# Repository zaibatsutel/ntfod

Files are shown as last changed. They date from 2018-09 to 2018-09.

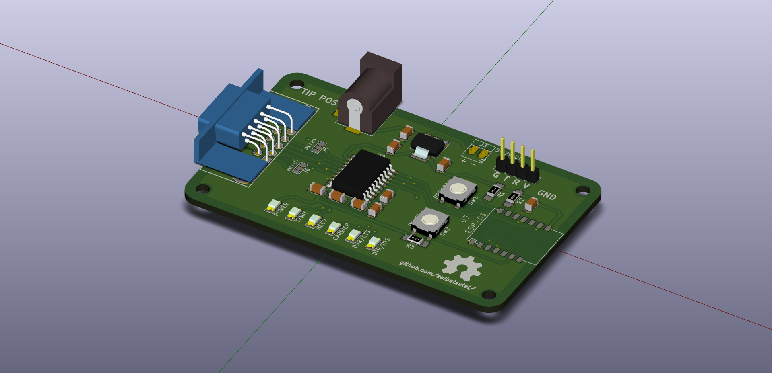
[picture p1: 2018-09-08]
boardshots/oblique-2018-09-08.png

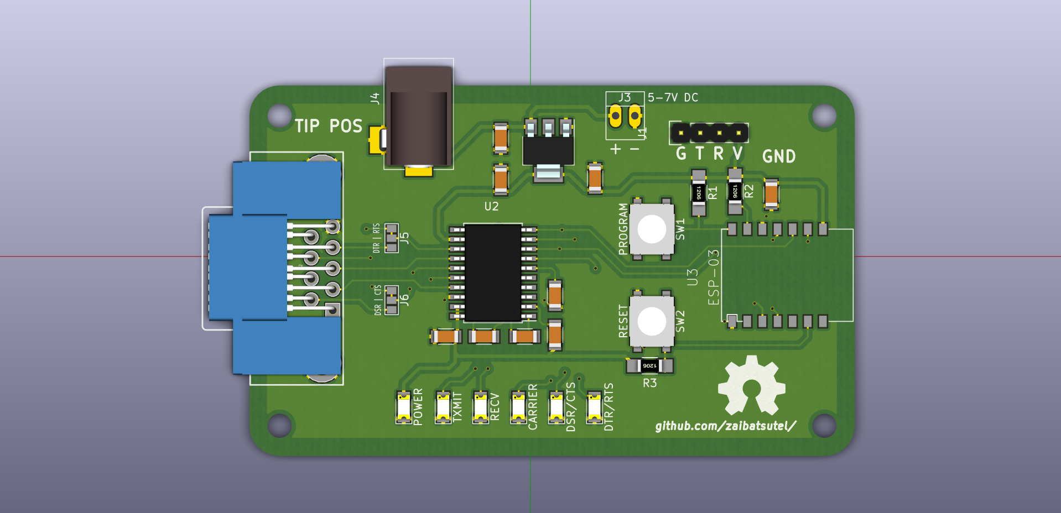
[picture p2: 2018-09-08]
boardshots/top-2018-09-08.png

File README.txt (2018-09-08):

HELLO INTERNET!

This is my version of the ever popular "connect your old computer to the
internet using wifi" project. 

This version uses (for now) the ESP-03, a slightly more broken out version
of the ESP-01. It has LEDs and stuff on it to show the state of control
registers and other things. 

The big thing that I wanted to implement here is that the flow control pins
are selectable!

There's some other things that I've done:

* I've used a MAX3386e (the SOIC20 version) so that I can make sure that I
have a good set of inputs and outputs. The big reason for this was so that
I can include a RING line (so you can dial into this!) and so that it had
all the various control lines that people integrated into their stuff.

Some day, I'd like to make this into a more product-like thing. 

The software is the apache2-licensed Zimodem from Bo Zimmerman. I'd like to
eventually have his software selectable in terms of what board it's being run
under so that there's fewer forks. His was designed with Commodore CBM machines
in mind -- mine is more build for the NEC Model 100s and friends. 

You can program this with the serial port that is included on the board if you
have a USB-Serial contrller, but you still have to populate the buttons for
program and reset.

Programming involves holding down program and reset, then releasing reset.
This will place the device into boot mode (as is the case with all the various
things that use the ESP8266.

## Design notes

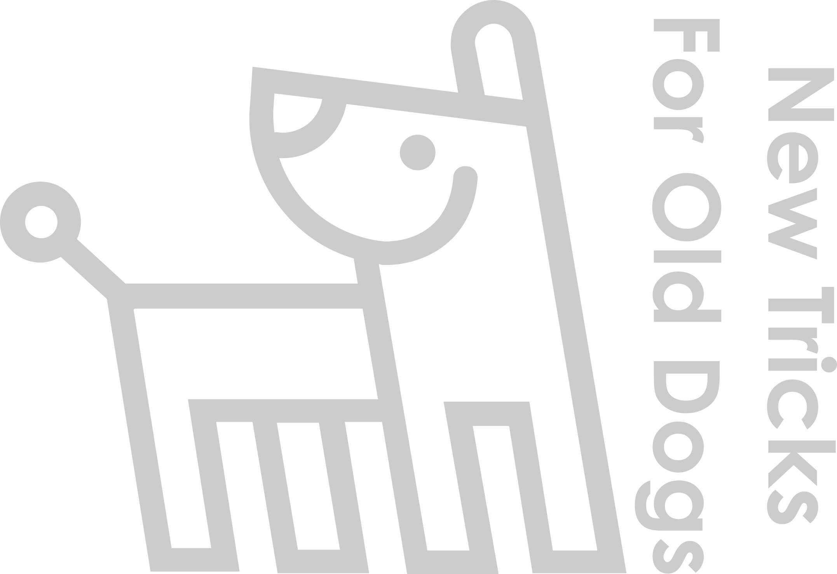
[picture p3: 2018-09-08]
graphics/path62.png

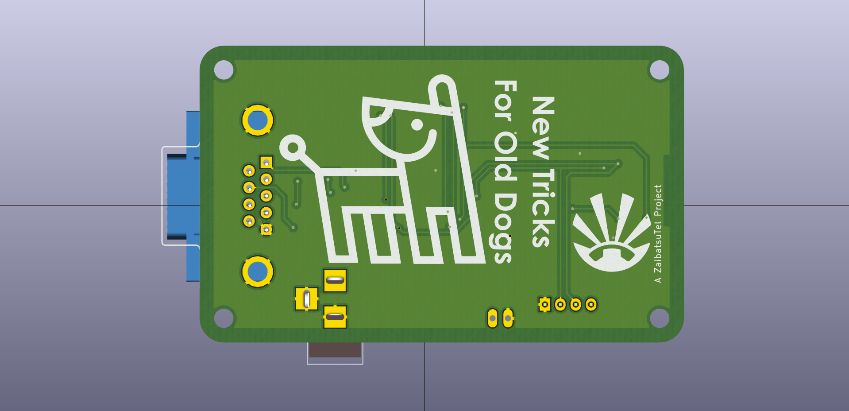
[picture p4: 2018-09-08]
boardshots/bottom-2018-09-08.png

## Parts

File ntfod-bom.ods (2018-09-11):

New Tricks for Old Dogs rev 2 initial BOM
reference | part | Part Number | DigiKey PN | Digikey qty1 | Digikey qty10 | Mouser PN | Mouser qty1 | Mouser qty10 | qty/board | Qty/10 | Digikey cost/1 | Digikey cost/10 | Mouser cost/1 | Mouser cost/10
D1-D6 | LED, 1206 smt | Lite-On LTST-C230KFKT | 160-2025-1-ND | $0.38 | $0.27 | 859-LTST-C230KFKT | $0.30 | $0.16 | 6 | 60 | $2.28 | $16.26 | $1.80 | $9.60
SW1 SW2 | SWITCH TACTILE SPST-NO 0.05A 12V | E-Switch TL3342F160QG/TR | EG2531CT-ND | $0.70 | $0.67 | 612-TL3342F160 | $0.66 | $0.63 | 2 | 20 | $1.40 | $13.40 | $1.32 | $12.60
U1 | IC REG LINEAR 3.3V 1A SOT223 | Diodes Incorporated AZ1117H-3.3TRE1 | AZ1117H-3.3TRE1DICT-ND | $0.47 | $0.35 | 621-AZ1117H-3.3TRE1 | $0.46 | $0.32 | 1 | 10 | $0.47 | $3.50 | $0.46 | $3.19
U2 | IC TXRX RS232 SPLIT SUPP 20SOIC | Texas Instruments TRS3386ECDWR | 296-25063-1-ND | $3.39 | $3.05 | 595-TRS3386ECDWR | $3.30 | $2.96 | 1 | 10 | $3.39 | $30.47 | $3.30 | $29.60
J2 | CONN D-SUB RCPT 9POS R/A SOLDER | Amphenol LD09S13A4GX00LF | 609-5189-ND | $0.98 | $0.86 | 649-LD09S13A4GX00LF | $0.99 | $0.86 | 1 | 10 | $0.98 | $8.60 | $0.99 | $8.64
J1 | CONN HEADER 4 POS 2.54 | Wurth 61300411121 | 732-5317-ND | $0.18 | $0.15 | 710-61300411121 | $0.18 | $0.15 | 1 | 10 | $0.18 | $1.53 | $0.18 | $1.53
J4 | CONN PWR JACK 2X5.5MM SOLDER | CUI PJ-002A | CP-002A-ND | $0.61 | $0.57 | 490-PJ-002A | $0.60 | $0.56 | 1 | 10 | $0.61 | $5.70 | $0.60 | $5.59
C2,C3,C4,C8 | Capacitor, 0.1ufd 1206 size | Wurth 885012208009 | 732-8086-1-ND | $0.11 | $0.10 | 710-885012208009 | $0.11 | $0.10 | 4 | 40 | $0.44 | $3.96 | $0.44 | $4.00
C1,C5,C7,C9,C6 | Capacitor 10ufd 1206 size | Taiyo-Yuden LMK316B7106KL-TD | 587-2596-1-ND | $0.30 | $0.21 | 963-LMK316BJ106ML-T | $0.29 | $0.13 | 5 | 50 | $1.50 | $10.35 | $1.45 | $6.40
R1,R2,R3 | Resistor, 10K 1206 SMT 5% | Rohm KTR18EZPJ103 | RHM10KPCT-ND | $0.15 | $0.14 | 755-KTR18EZPJ103 | $0.13 | $0.11 | 3 | 30 | $0.45 | $4.11 | $0.39 | $3.36
U3 | ESP8266 ESP-03 module | AI-thinker ESP-03 | N/A |  |  | N/A
 |  |  | DigiKey cost/1 | 11.7
 |  |  | DigiKey Cost/10 | 97.88
 |  |  | Mouser cost/1 | 10.93
 |  |  | Mouser cost/10 | 84.51
AliExpress vendors for ESP-03 module
1pc vendor A | $1.95 | https://www.aliexpress.com/store/product/1PC-ESP8266-serial-WIFI-model-ESP-03-Authenticity-Guaranteed-esp03/1735233_32641401163.html
10pc/lot via Mega Semiconductor | $22.00 | https://www.aliexpress.com/store/product/Free-Shipping-10pcs-lot-ESP8266-remote-serial-Port-WIFI-wireless-module-through-walls-Wang-ESP-03/808897_32713422494.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
1pc/lot via Mega Semiconductor | $2.15 | https://www.aliexpress.com/store/product/ESP8266-serial-WIFI-model-ESP-03-Authenticity-Guaranteed-ESP03-free-shipping/808897_32713916387.html
5pcs/lot via Best Choice | $12.40 | https://www.aliexpress.com/store/product/Free-shipping-5-PCS-ESP8266-SMD-serial-WIFI-industry-milepost-unbeatable-price-deep-Mingyang-Electronics-ESP/221555_3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
10pc/lot via Annousen | $32.00 | https://www.aliexpress.com/store/product/10-PCS-LOT-ESP8266-ESP-03-serial-WIFI-WIF-transceiver-wireless-remote-wireless-control-module-ESP/3632102_32854430232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
Cost to build 5 w/mouser | 54.65
Cost to build 5 w/digikey | 58.5
Mouser cost 5 + Aliexpress | $67.05 |  | Long lead time on ESP8266, 20-40 days!

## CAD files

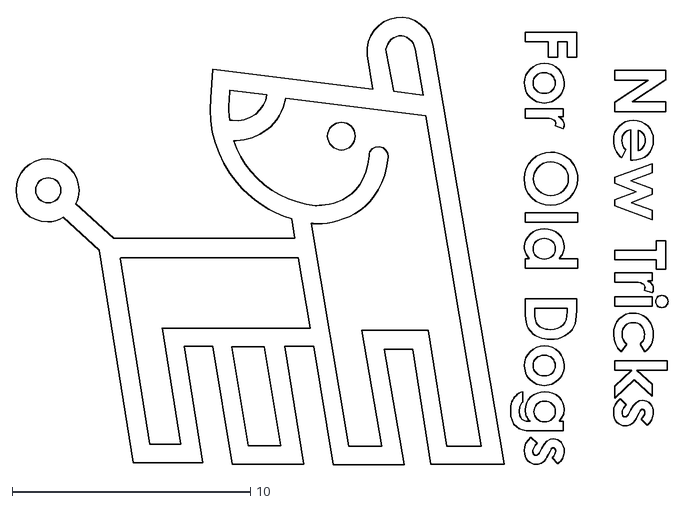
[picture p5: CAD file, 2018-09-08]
graphics/logo.dxf
27.4 x 18.8

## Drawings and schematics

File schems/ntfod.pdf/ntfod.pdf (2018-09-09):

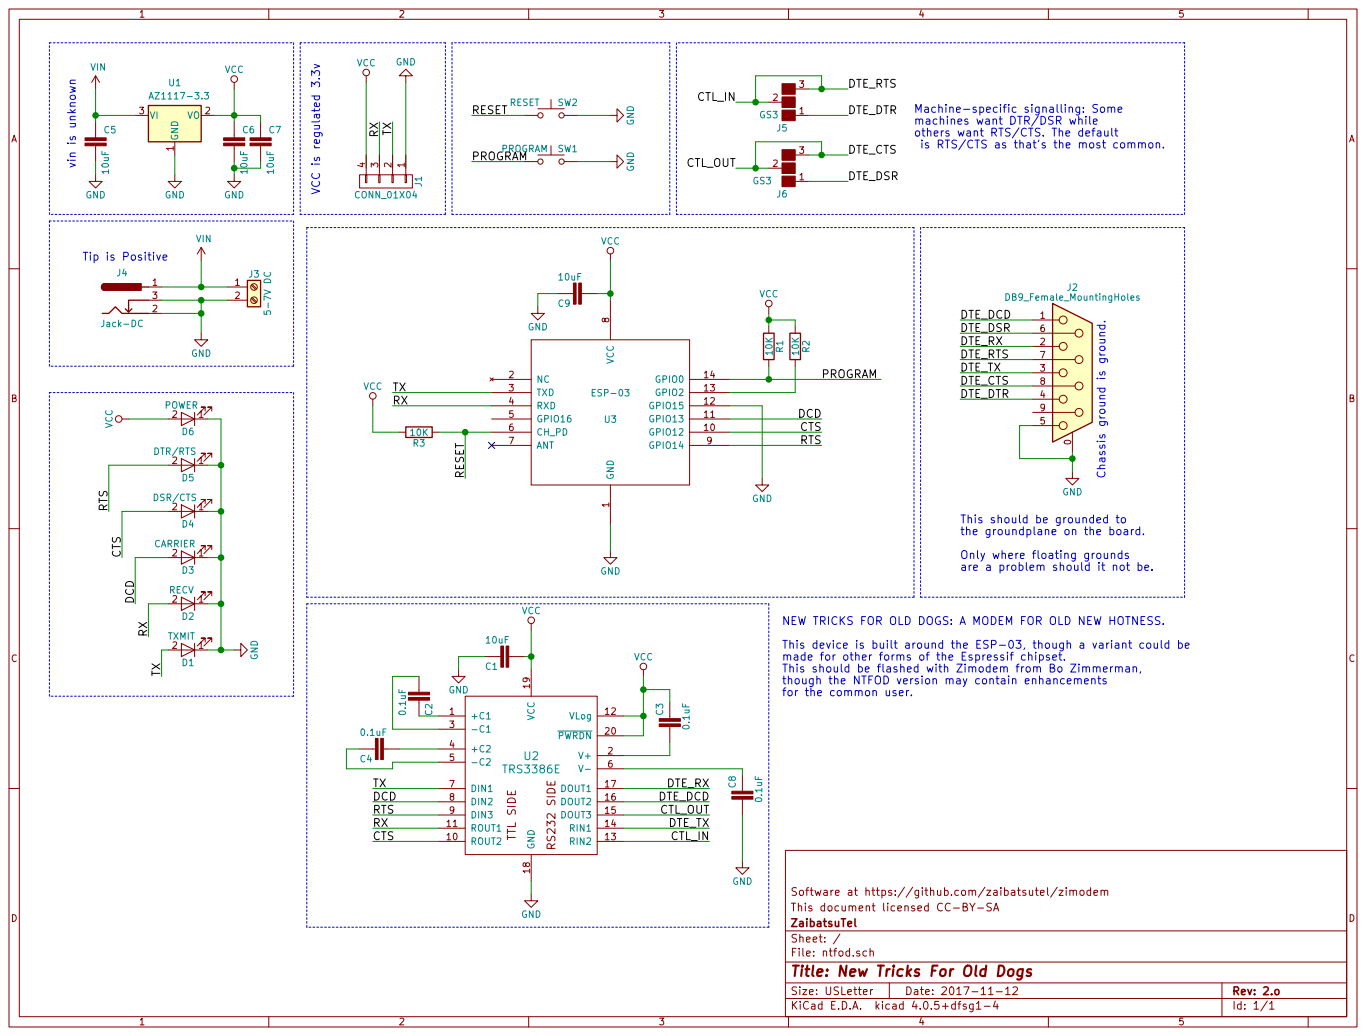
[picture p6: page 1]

Machine-specific signalling: Some
machines want DTR/DSR while
others want RTS/CTS. The default
is RTS/CTS as that's the most common.

This should be grounded to
the groundplane on the board.
Only where floating grounds
are a problem should it not be.

NEW TRICKS FOR OLD DOGS: A MODEM FOR OLD NEW HOTNESS.
This device is built around the ESP-03, though a variant could be
made for other forms of the Espressif chipset.
This should be flashed with Zimodem from Bo Zimmerman,
though the NTFOD version may contain enhancements

File: ntfod.sch Sheet: / ZaibatsuTel This document licensed CC-BY-SA

Id: 1/1 Title: New Tricks For Old Dogs

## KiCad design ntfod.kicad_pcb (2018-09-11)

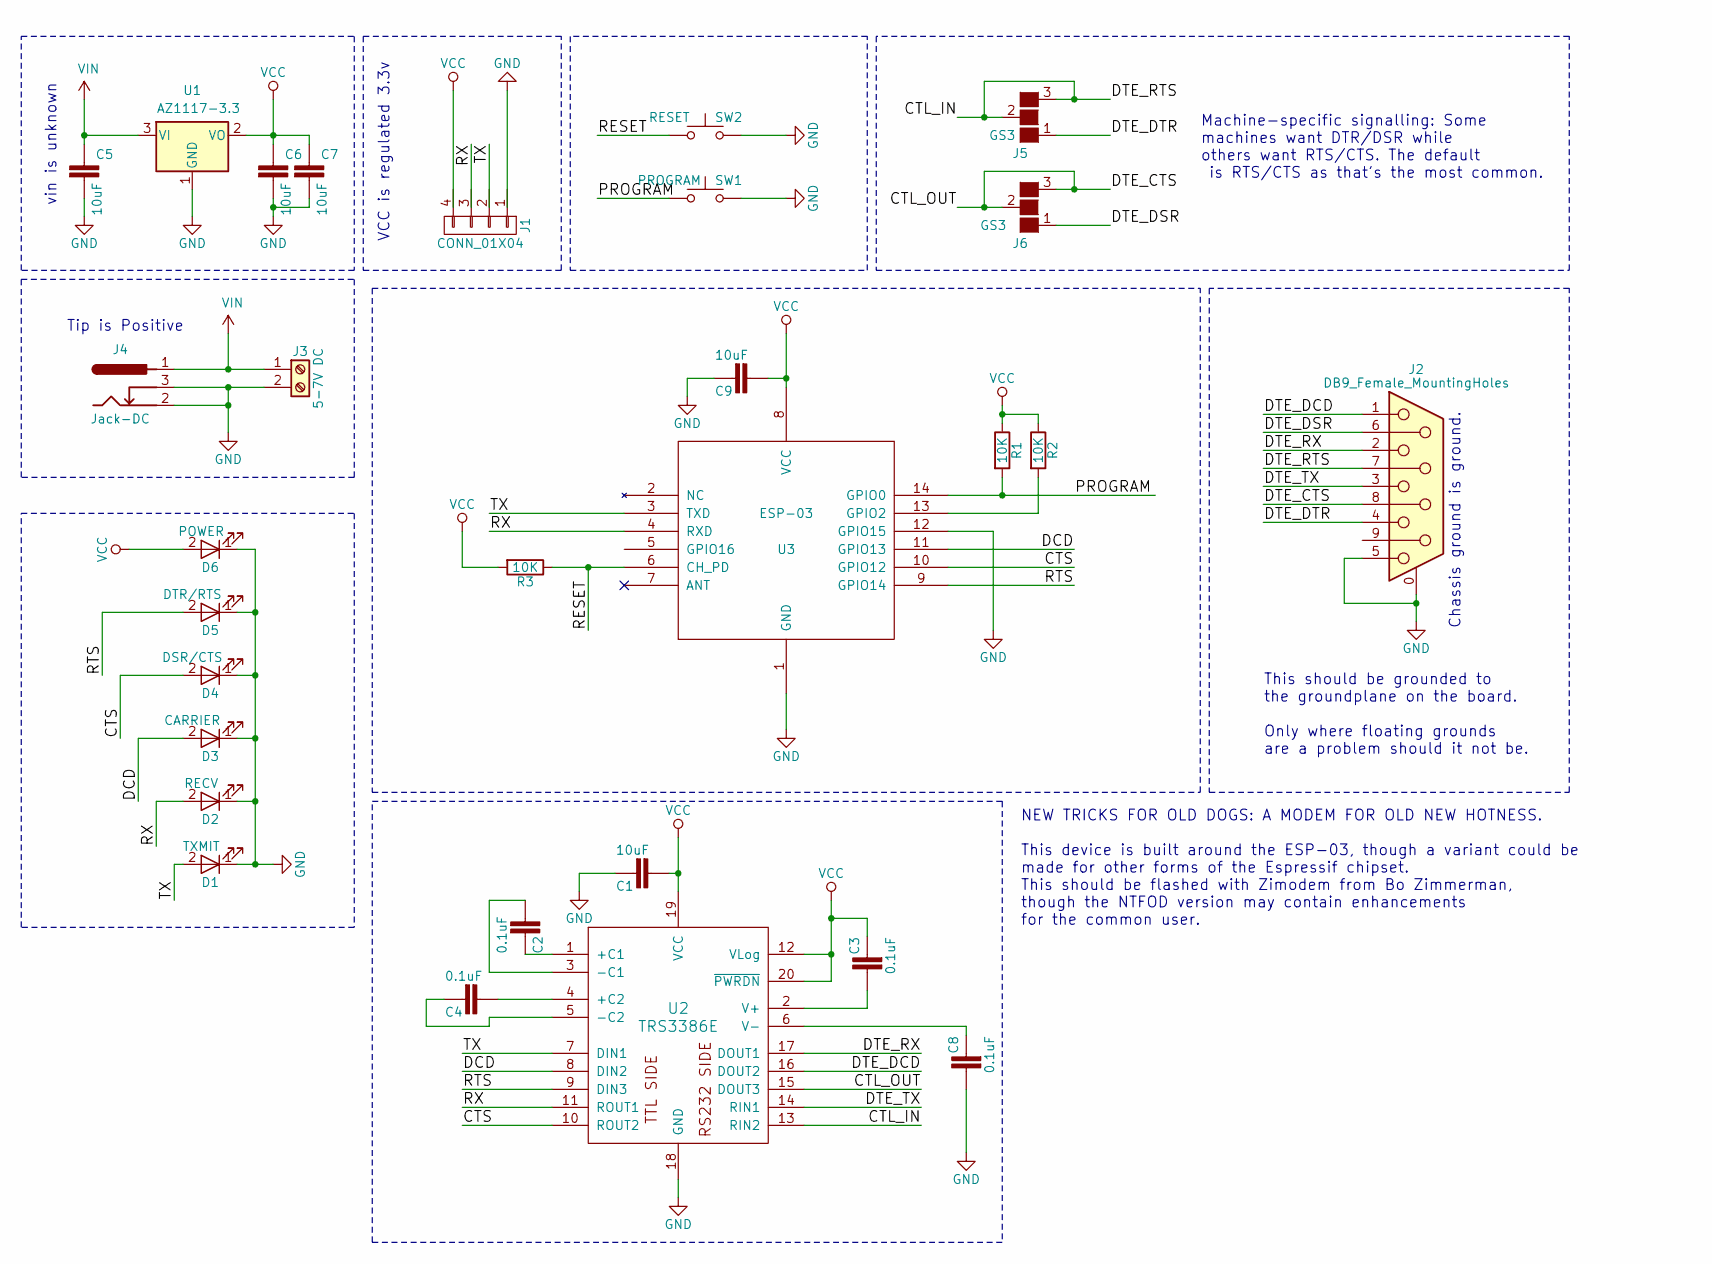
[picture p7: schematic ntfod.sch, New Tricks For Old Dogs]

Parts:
C1, C5, C6, C7, C9: 10uF; 1206
C2, C3, C4, C8: 0.1uF; 1206
D1: TXMIT; D_1206
D2: RECV; D_1206
D3: CARRIER; D_1206
D4: DSR/CTS; D_1206
D5: DTR/RTS; D_1206
D6: POWER; D_1206
J1: CONN_01X04; Pin_Header_Straight_1x04
J2: DB9_Female_MountingHoles; DB9
J3: 5-7V DC; PINHEAD1-2
J4: Jack-DC; BARREL_JACK
J5, J6: GS3
R1, R2, R3: 10K; R_1206_HandSoldering
SW1: PROGRAM; SW_SPST_TL3342
SW2: RESET; SW_SPST_TL3342
U1: AZ1117-3.3; SOT-223-3_TabPin2
U2: TRS3386E; SOIC-20W_7.5x12.8mm_Pitch1.27mm
U3: ESP-03

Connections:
/CTL_IN: J2.7, J5.2 (G2), J5.3 (G3), U2.13 (RIN2)
/CTL_OUT: J2.8, J6.2 (G2), J6.3 (G3), U2.15 (DOUT3)
/CTS: D4.2 (A), U2.10 (ROUT2), U3.10 (GPIO12)
/DCD: D3.2 (A), U2.8 (DIN2), U3.11 (GPIO13)
/DTE_DCD: J2.1, U2.16 (DOUT2)
/DTE_DSR: J2.6, J6.1 (G1)
/DTE_DTR: J2.4, J5.1 (G1)
/DTE_RX: J2.2, U2.17 (DOUT1)
/DTE_TX: J2.3, U2.14 (RIN1)
/PROGRAM: R1.2, SW1.1, U3.14 (GPIO0)
/RESET: R3.1, SW2.1, U3.6 (CH_PD)
/RTS: D5.2 (A), U2.9 (DIN3), U3.9 (GPIO14)
/RX: D2.2 (A), J1.3, U2.11 (ROUT1), U3.4 (RXD)
/TX: D1.2 (A), J1.2, U2.7 (DIN1), U3.3 (TXD)
GND: C1.2, C5.2, C6.2, C7.2, C8.1, C9.2, D1.1 (K), D2.1 (K), D3.1 (K), D4.1 (K), D5.1 (K), D6.1 (K), J1.1, J2.0 (PAD), J2.5, J3.2, J4.2, J4.3, SW1.2, SW2.2, U1.1 (GND), U2.18 (GND), U3.1 (GND), U3.12 (GPIO15)
unnamed: C2.1, U2.3 (-C1)
unnamed: C2.2, U2.1 (+C1)
unnamed: C3.1, U2.2 (V+)
unnamed: C4.1, U2.4 (+C2)
unnamed: C4.2, U2.5 (-C2)
unnamed: C8.2, U2.6 (V-)
unnamed: R2.2, U3.13 (GPIO2)
VCC: C1.1, C3.2, C6.1, C7.1, C9.1, D6.2 (A), J1.4, R1.1, R2.1, R3.2, U1.2 (VO), U2.12 (VLog), U2.19 (VCC), U2.20 (~PWRDN), U3.8 (VCC)
VIN: C5.1, J3.1, J4.1, U1.3 (VI)

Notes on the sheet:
vin is unknown
VCC is regulated 3.3v
Tip is Positive
Chassis ground is ground.
Machine-specific signalling: Some machines want DTR/DSR while others want RTS/CTS. The default is RTS/CTS as that's the most common.
This should be grounded to the groundplane on the board. Only where floating grounds are a problem should it not be.
NEW TRICKS FOR OLD DOGS: A MODEM FOR OLD NEW HOTNESS. This device is built around the ESP-03, though a variant could be made for other forms of the Espressif chipset. This should be flashed with Zimodem from Bo Zimmerman, though the NTFOD version may contain enhancements for the common user.

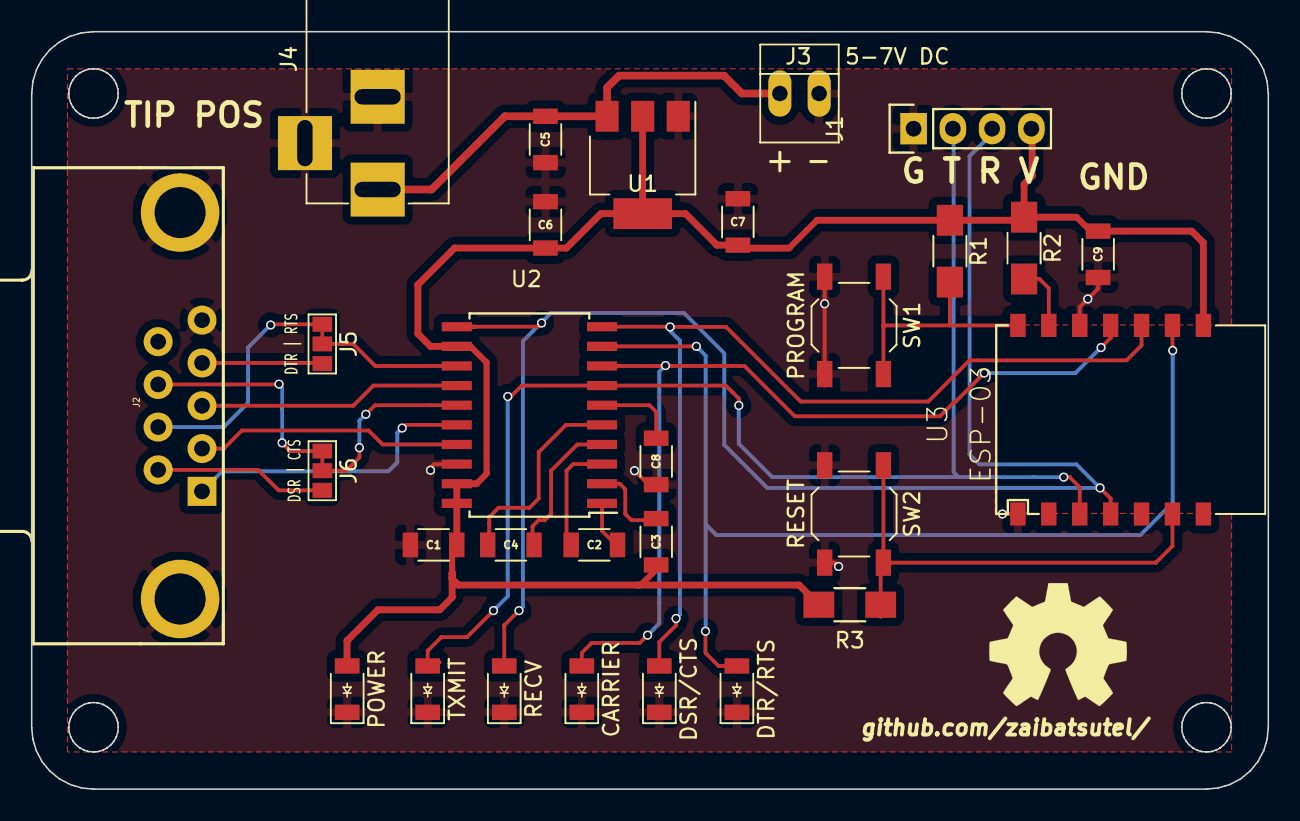
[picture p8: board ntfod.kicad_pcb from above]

Board: 2 copper layers, 80.0 x 49.0 mm, 29 parts (0 on the bottom side), 24 nets.

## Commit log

2018-09-08 initial commit.
    [logo.dxf, ntfod.kicad_pcb, ntfod.sch]
2018-09-08 Initial board shots
2018-09-09 Initial gerber and schematic pdfs
    This is revision 2: The first revision I care to release to the world.
    I'll tell you how it goes when I have actual, physical boards in my
    actual physical hands.
    [ntfod-B.Cu.gbl, ntfod-B.Mask.gbs, ntfod-B.SilkS.gbo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]
2018-09-11 initial BOM, PCB finish.
    [ntfod-bom.ods, ntfod.kicad_pcb]
